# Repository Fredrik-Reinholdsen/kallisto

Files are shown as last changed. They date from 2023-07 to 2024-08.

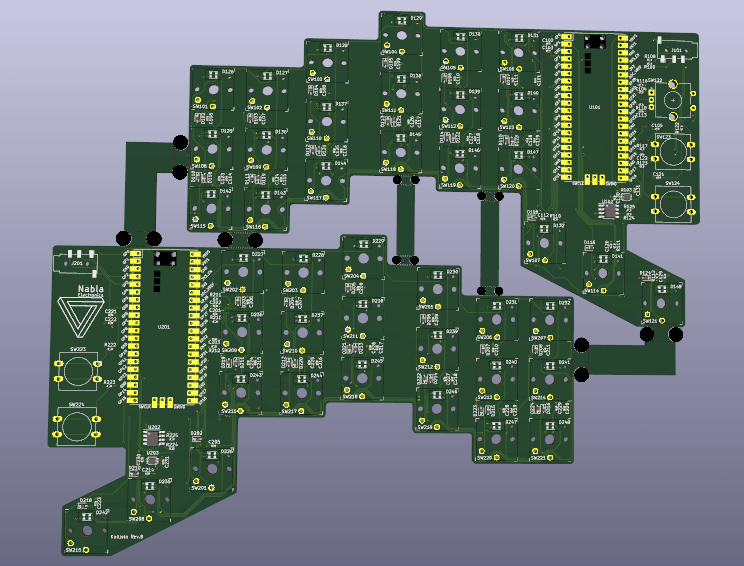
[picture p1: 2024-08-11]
images/kallisto_3dmodel.png

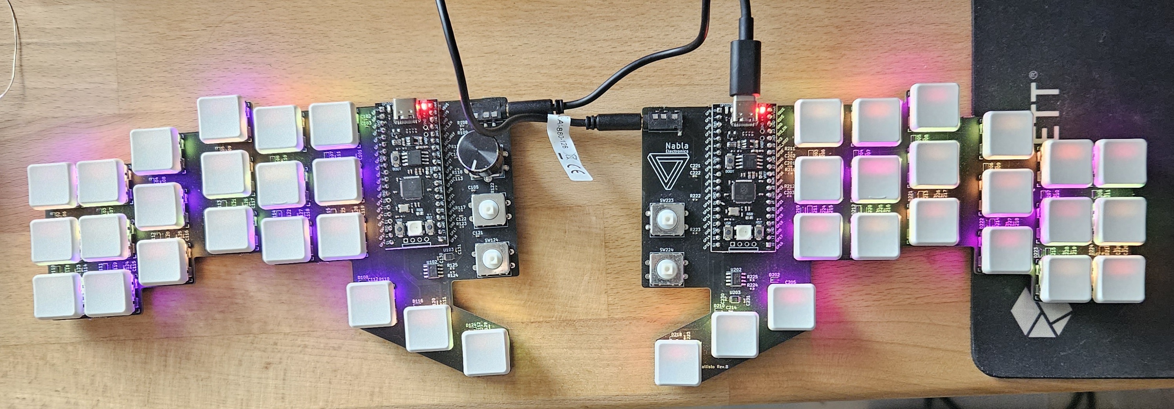
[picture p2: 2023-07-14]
images/kallisto.jpg

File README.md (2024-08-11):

# Kallisto

A custom split keyboard, with custom electronics and firmware.

kallisto

The hardware is based around a variant of the _Raspberry Pi Pico_ board, and the _RP2040_ microcontroller.
The keyboard features:

- 42 Kailh 1350 mechanical keyswitches (21 per half), 4 extra buttons and one rotary encoder.
- Fully programmable key-map were any key can be mapped to any key/media function.
- Key-map Layers
- Custom RGB lighting with adjustable brightness
- Onboard flash memory that hold the key-map.

All electronics were designed using KiCad, and all firmware is written in Rust.

## Key Mapping
Any physical key on the keyboard may be mapped to any key, with or without an additional modifier.
Buttons have a few different press modes, similar to the *QMK* firmware, that you can map separatley to different keys.

The different key press types/events are:
- Press
- Held Press
- Double Press

### Held Press
A held press is when a button is pressed and held, for a set ammount of time (0.5s by default).
If a button has a held press mapping is pressed and then released before the held-time window,
then the regular _Press_ mapping while fire upon the release, not the press.
If another button is pressed before the end of the held-time window, then the held press mapping while fire immediatley,
and the other pressed button will fire right after.
If a button with a held press mapping is pressed and held for more than the held-time window, and no other button is pressed in between,
then the held press key mapping will fire.

## Software Design
The right half of the keyboard connected to the host PC acts as the master, and the the left half as the slave.
Compiling the embedded software will generate two separate binaries, one for the master half, and one for the slave.

The slave software is very light-weight and is basically only reading the button matrix, and communicating the current
button states to the master half vi I2C. This means that the slave, once flashed, should rarely need to be re-programmed since the
vast majority of the more complicated application code is running on the master half.

Below is a figure showing the overall architecture of the software that is running on each half of the keyboard.
```mermaid
flowchart RL
    subgraph Master
        direction BT
        BMR[Button Matrix] --> KEGR(Key Event Generator)
        KEGR -->|Key Event| BEG(Button Event Generator)
        BEG -->|Button Event| BEM(Button Event Mapper)
        BEM -->|USB HID Event| USB(USB HID)
    end

    subgraph Slave
        direction BT
        BML[Button Matrix] --> KEGL(Key Event Generator)
    end

    Slave -->|Key Events| Master
```
### Key Event Generator
The `Key Event Generator` reads the current states of all keyboard buttons from the button matrix driver, and generates key press events.
Either key-down or key-up events, based on the current, and the previous button states. Key press events and IDs are constantly
streamed from the slave to the master half via I2C.
These key events from both halves are then queued on the master, along with a unique button ID for which physical button that triggered the event.

### Button Event Generator
The `Button Event Generator` then reads the incoming key press events, and correspoding button IDs from the key-event queue.
This information is then used to generate `Button Events`. The different kinds are:
- Single Press
- Held Press
- Double Press

A held press is triggered if a button is pressed and held for more than 0.3 seconds, and a double press is generated
if a button is pressed twice within 0.3 seconds (these times are tweakable).

The button events along with the ID of which physical button produced the event are then passed `Button Event Mapper`

### Button Event Mapper
The `Button Event Mapper` then maps the incoming button IDs and button event types to a key-press to be sent to the host PC via USB.
For example, single pressing the z-key might map to `z`, but pressing and hold it might map to `Ctrl`. This mapping for each physical button,
and button event type is fully customizable.

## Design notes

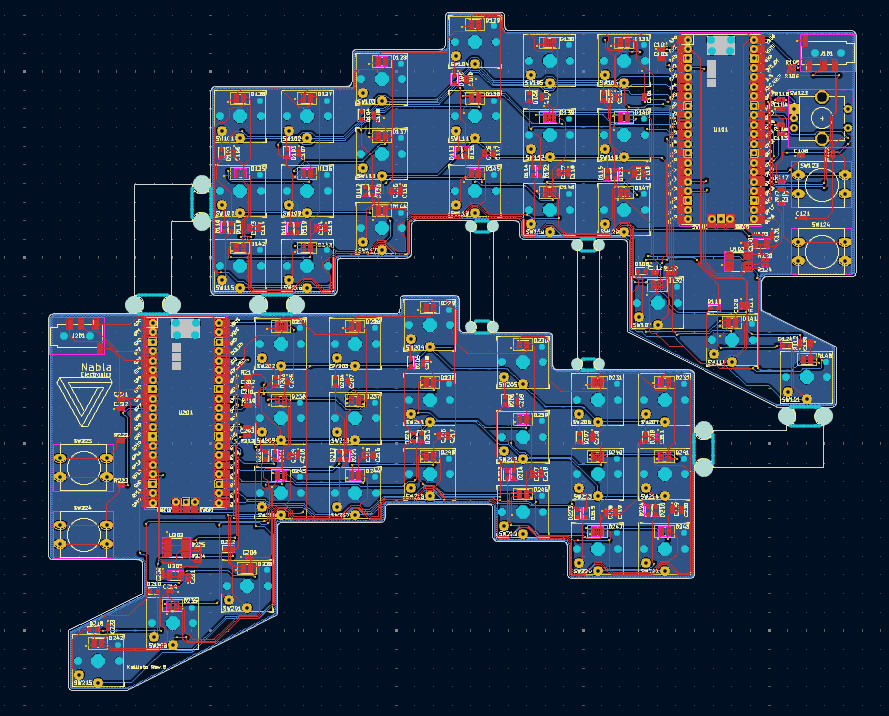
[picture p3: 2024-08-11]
images/kallisto_pcb.png

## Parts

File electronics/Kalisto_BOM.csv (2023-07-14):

Comment | Designator | Footprint | LCSC Part #
100n | C101,C102,C103,C104,C106,C107,C108,C109,C110,C111,C112,C113,C114,C115,C116,C117,C118,C119,C120,C123,C124,C125,C126,C127,C128,C129,C130,C131,C201,C202,C203,C205,C206,C207,C208,C209,C210,C211,C214,C215,C216,C217,C218,C219,C220,C223,C224,C225,C226,C227,C228,C229,C230,C231 | C_0402_1005Metric | C1525
220n | C105,C121,C122,C221,C222 | C_0402_1005Metric | C16772
1N4148 | D102,D103,D104,D105,D106,D107,D108,D110,D111,D112,D113,D114,D115,D116,D118,D119,D120,D121,D122,D123,D124,D202,D203,D204,D205,D206,D207,D208,D210,D211,D212,D213,D214,D215,D216,D218,D219,D220,D221,D222,D223,D224 | D_SOD-323 | C2128
WS2812B_2020 | D126,D127,D128,D129,D130,D131,D132,D135,D136,D137,D138,D139,D140,D141,D142,D143,D144,D145,D146,D147,D148,D226,D227,D228,D229,D230,D231,D232,D235,D236,D237,D238,D239,D240,D241,D242,D243,D244,D245,D246,D247,D248 | LED_WS2812B-2020_PLCC4_2.0x2.0mm | C965555
AudioJack4 | J101,J201 | Jack_3.5mm_PJ320D_Horizontal | C431535
4.7k | R108,R109,R110,R111,R112,R116,R117,R118,R122,R123,R124,R125,R210,R211,R212,R222,R223,R224,R225 | R_0402_1005Metric | C25900
Encoder | SW122 | RotaryEncoder_Alps_EC11E-Switch_Vertical_H20mm_CircularMountingHoles | C470753
SW_SPST | SW123,SW124,SW223,SW224 | SW_PUSH-12mm | C93155
AT24C256C-SSHL-T | U102,U202 | SOIC-8_3.9x4.9mm_P1.27mm | C6482
TXB0102DCU | U103,U203 | VSSOP-8_2.4x2.1mm_P0.5mm | C2677366

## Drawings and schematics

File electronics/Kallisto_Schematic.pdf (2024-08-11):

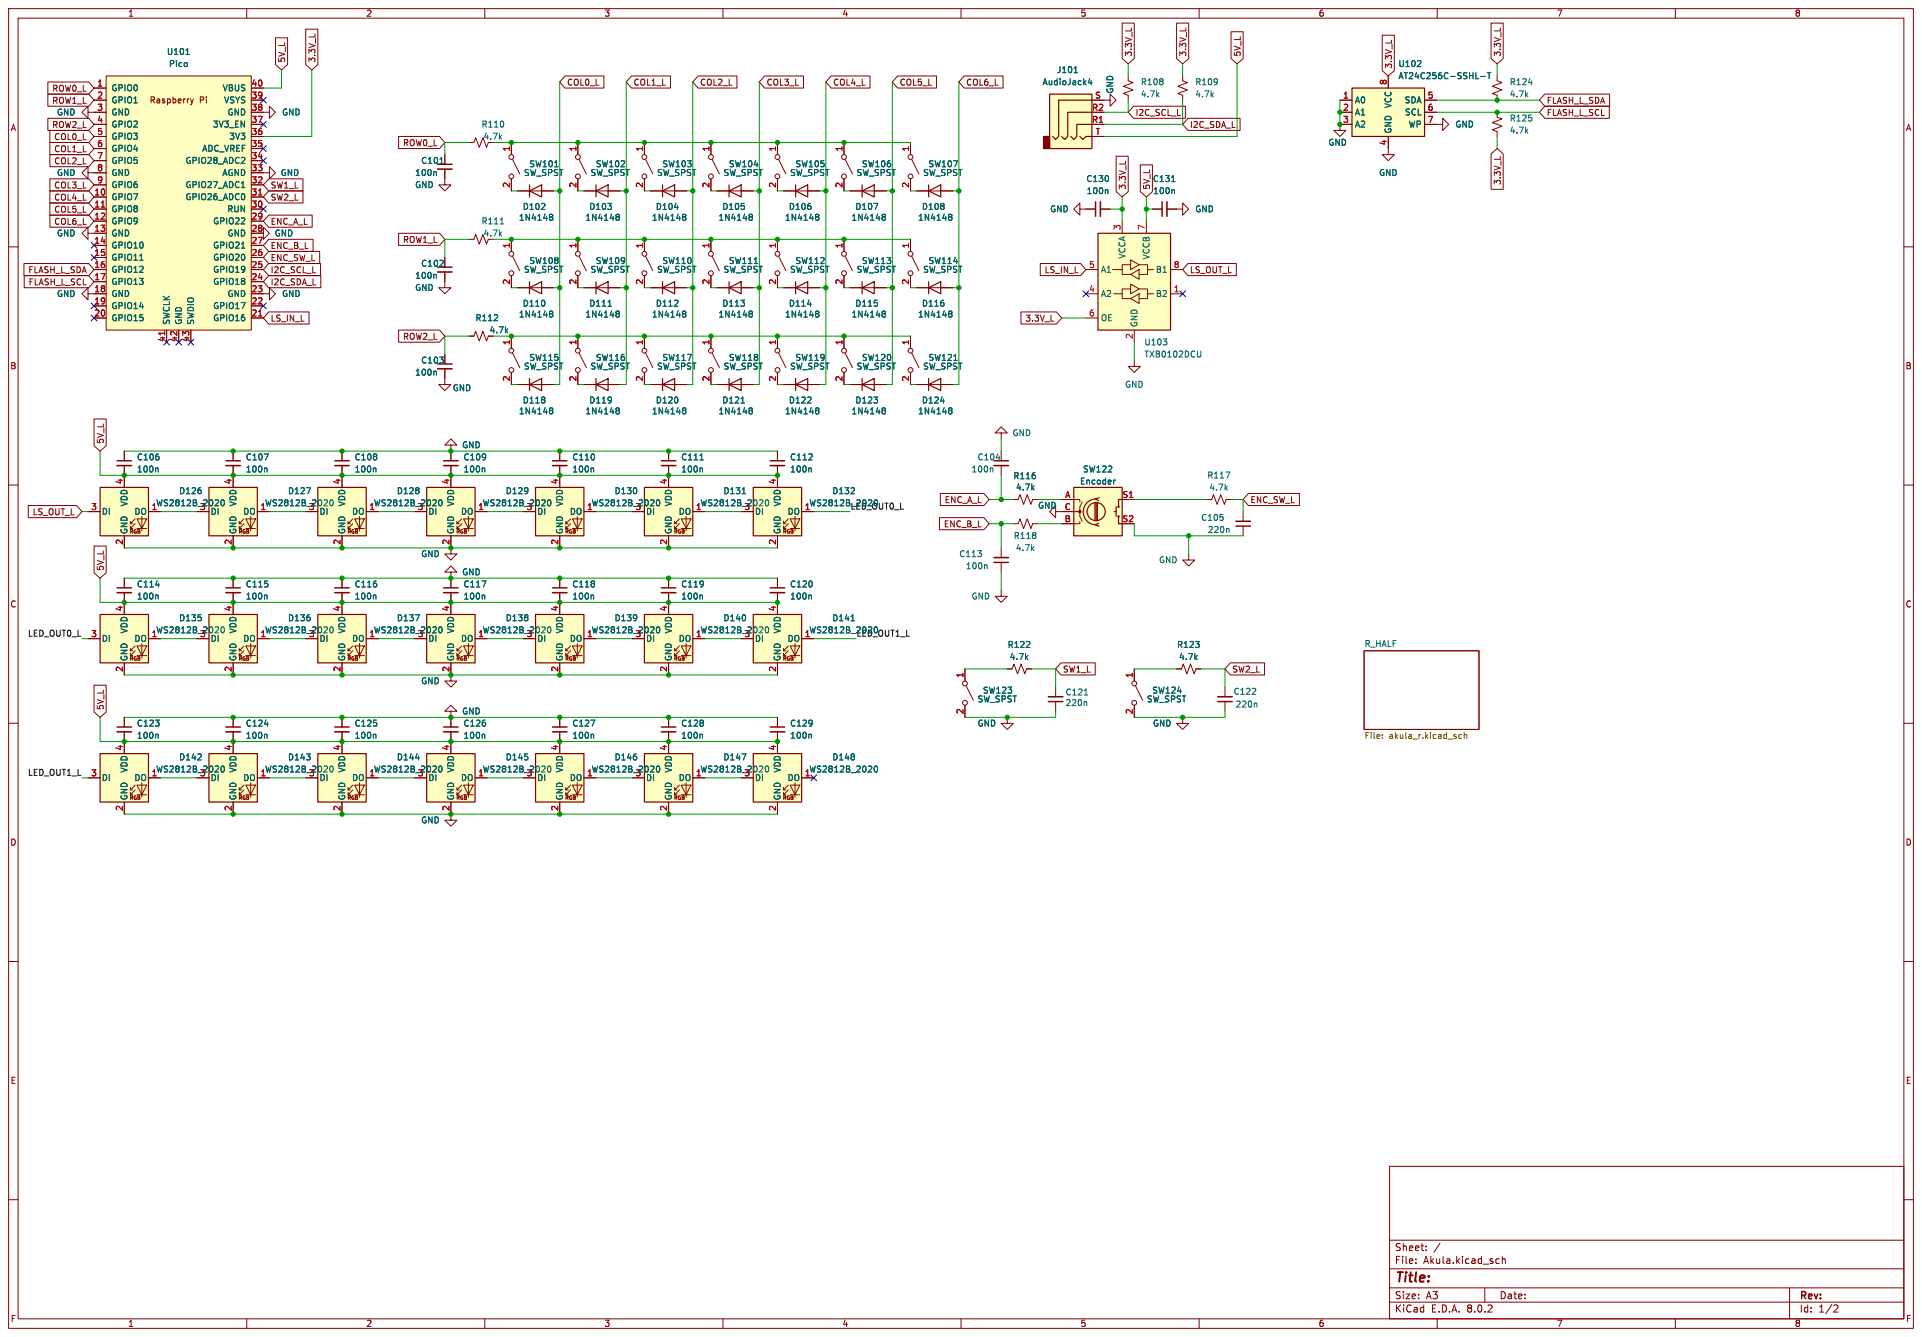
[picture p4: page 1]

4 D129 WS2812B_2020 Raspberry Pi GPIO0 1 GPIO7 10 GPIO8 11 GPIO9 12 GND 13 GPIO10 14 GPIO11 15 GPIO12 16 GPIO13 17 GND 18 GPIO14 19 GPIO1 2 GPIO15 20 GPIO16 21 GPIO17 22 GND 23 GPIO18 24 GPIO19 25 GPIO20 26 GPIO21 27 GND 28 GPIO22 29 GND 3 RUN 30 GPIO26_ADC0 31 GPIO27_ADC1 32 AGND 33 GPIO28_ADC2 34 ADC_VREF 35

4 SDA 5 SCL 6 WP 7 VCC

Id: 1/2 Title: File: Akula.kicad_sch Sheet: /

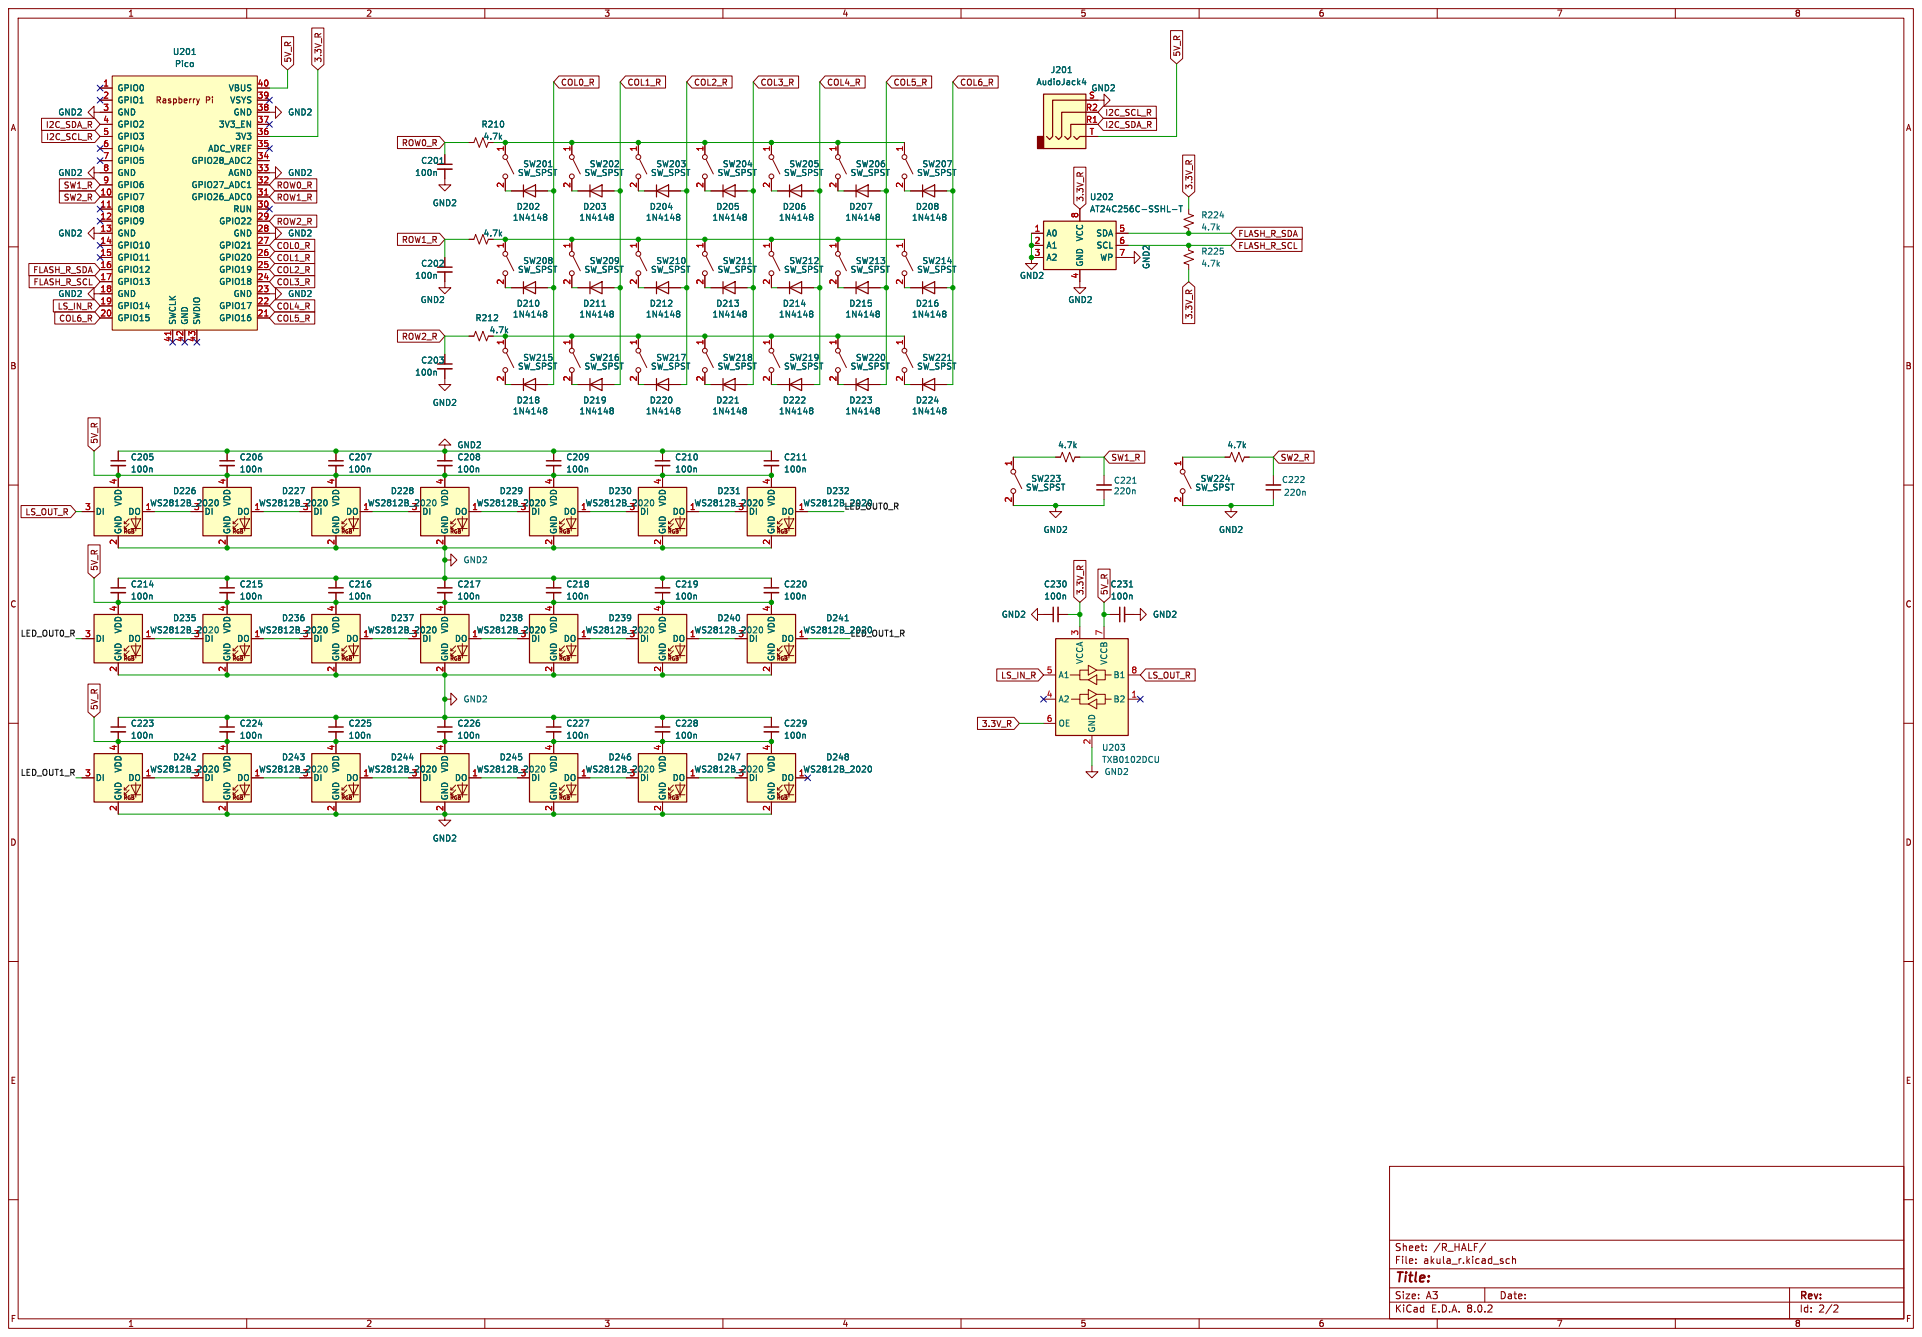
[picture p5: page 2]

4 U201 Pico GPIO0 1 GPIO7 10 GPIO8 11 GPIO9 12 GND 13 GPIO10 14 GPIO11 15 GPIO12 16 GPIO13 17 GND 18 GPIO14 19 GPIO1 2 GPIO15 20 GPIO16 21 GPIO17 22 GND 23 GPIO18 24 GPIO19 25 GPIO20 26 GPIO21 27 GND 28 GPIO22 29 GND 3 RUN 30 GPIO26_ADC0 31 GPIO27_ADC1 32 AGND 33 GPIO28_ADC2 34 ADC_VREF 35

4 SDA 5 SCL 6 WP 7 VCC
FLASH_R_SCL 5V_R

Id: 2/2 Title: File: akula_r.kicad_sch Sheet: /R_HALF/

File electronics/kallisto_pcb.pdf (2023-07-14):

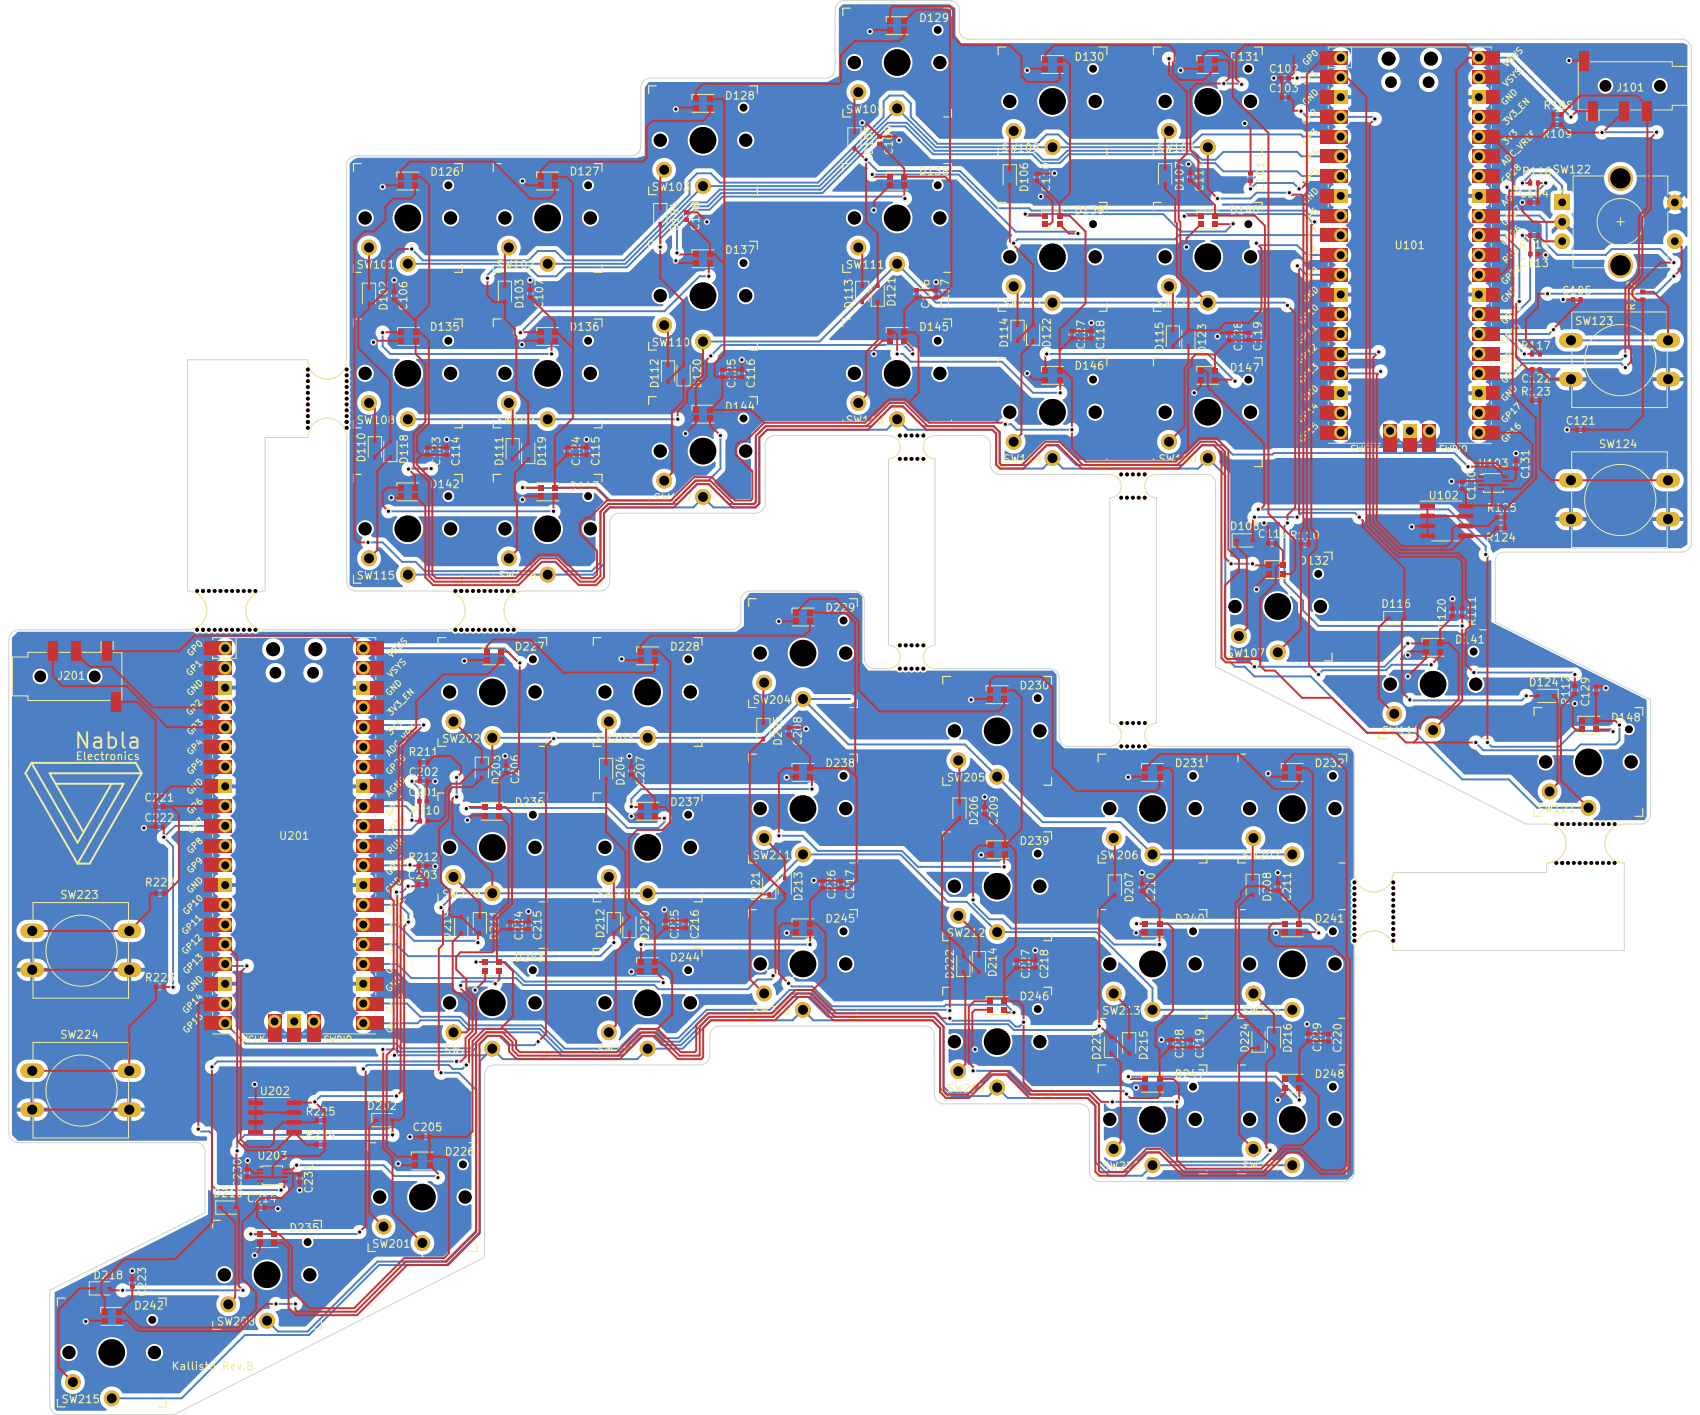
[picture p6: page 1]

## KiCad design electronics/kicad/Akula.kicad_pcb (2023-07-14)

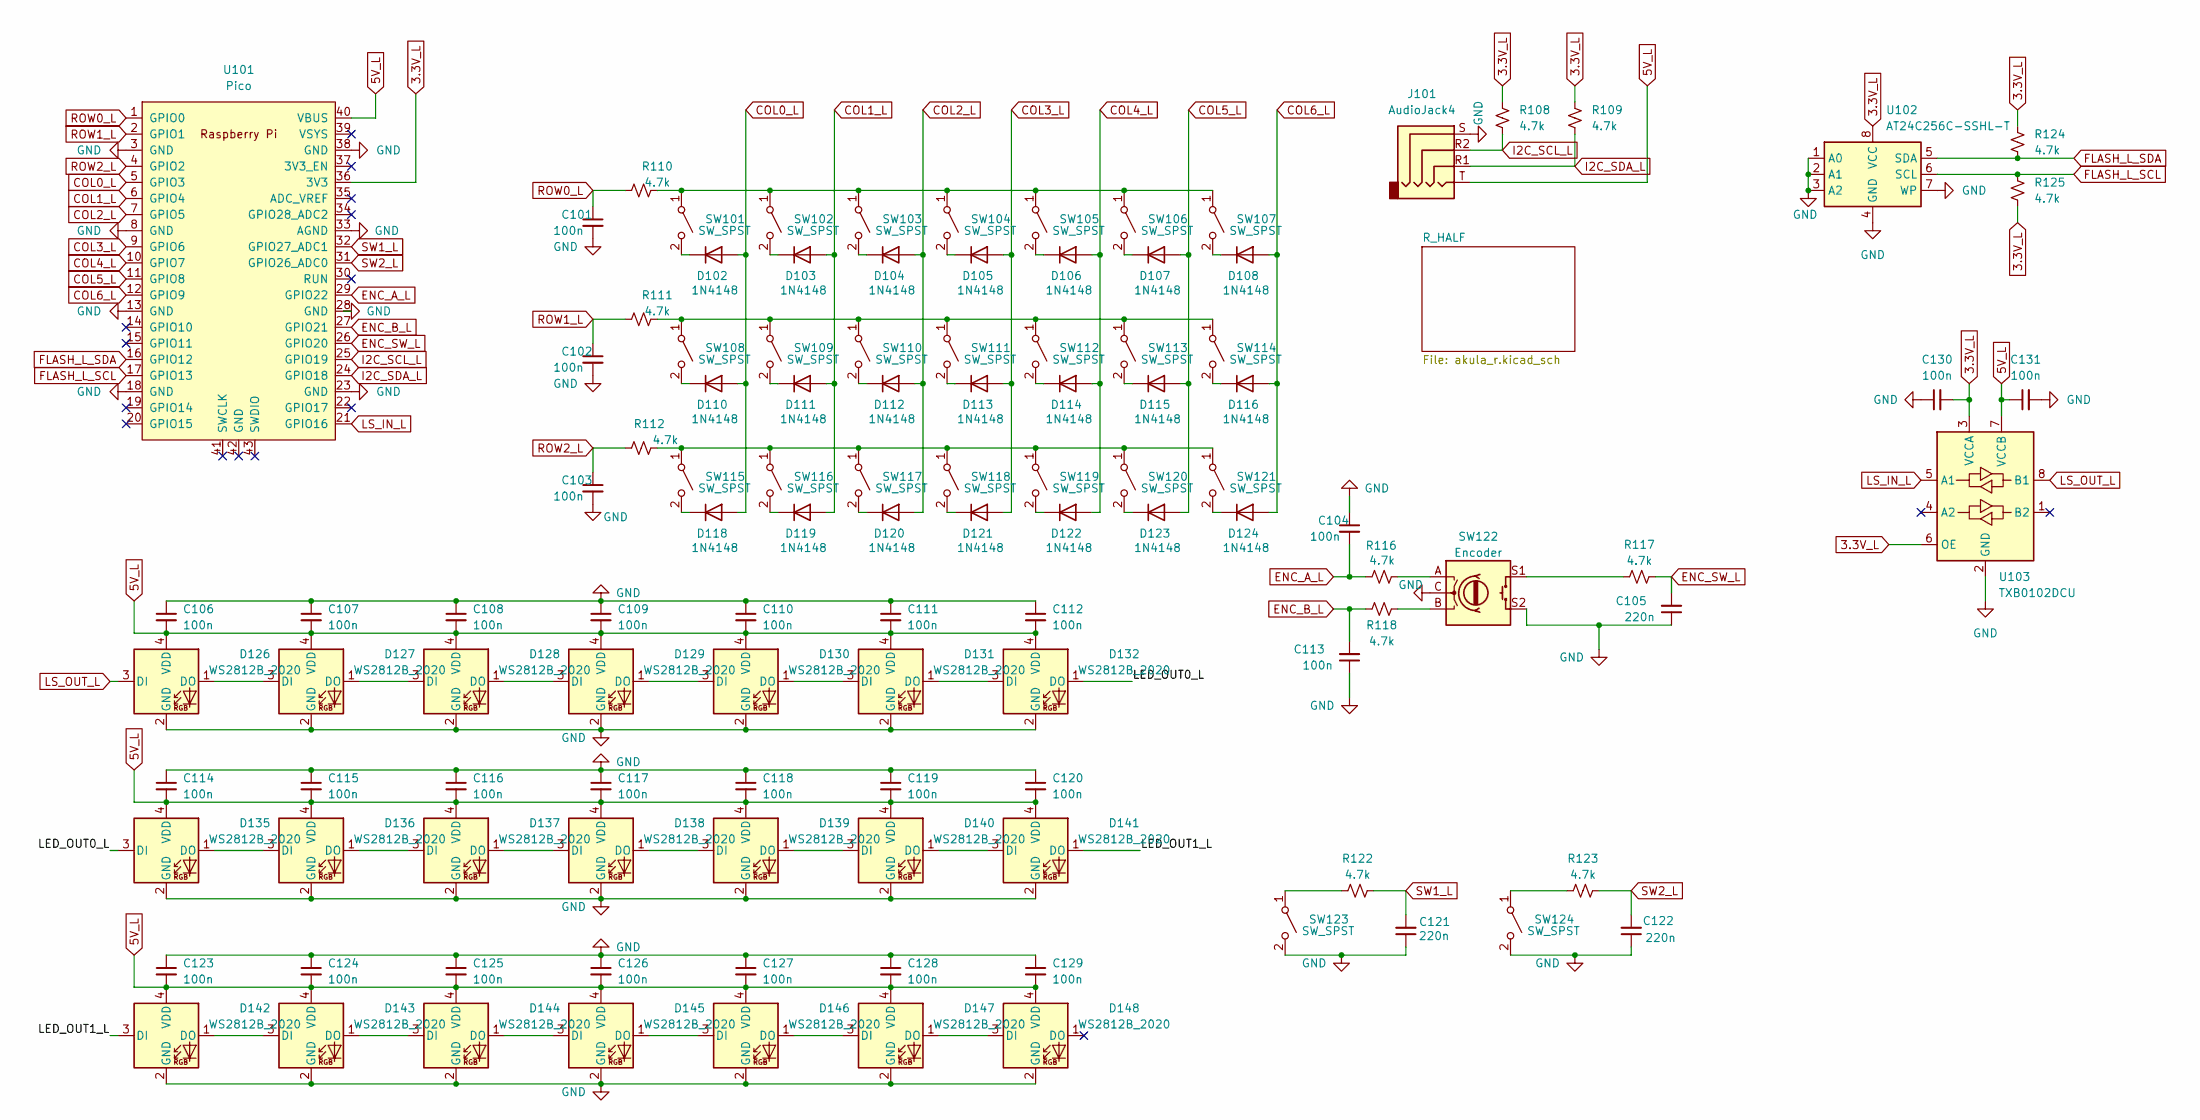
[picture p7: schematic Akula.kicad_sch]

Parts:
C101, C102, C103, C104, C106, C107, C108, C109, C110, C111, C112, C113, C114, C115, C116, C117, C118, C119, C120, C123, C124, C125, C126, C127, C128, C129, C130, C131: 100n; C_0402_1005Metric; JLCPCB Part # C1525
C105, C121, C122: 220n; C_0402_1005Metric; JLCPCB Part # C16772
D102, D103, D104, D105, D106, D107, D108, D110, D111, D112, D113, D114, D115, D116, D118, D119, D120, D121, D122, D123, D124: 1N4148; D_SOD-323; JLCPCB Part # C2128
D126, D127, D128, D129, D130, D131, D132, D135, D136, D137, D138, D139, D140, D141, D142, D143, D144, D145, D146, D147, D148: WS2812B_2020; LED_WS2812B-2020_PLCC4_2.0x2.0mm; JLCPCB Part # C965555
J101: AudioJack4; Jack_3.5mm_PJ320D_Horizontal; JLCPCB Part # C431535
R108, R109, R110, R111, R112, R116, R117, R118, R122, R123, R124, R125: 4.7k; R_0402_1005Metric; JLCPCB Part # C25900
SW101, SW102, SW103, SW104, SW105, SW106, SW107, SW108, SW109, SW110, SW111, SW112, SW113, SW114, SW115, SW116, SW117, SW118, SW119, SW120, SW121: SW_SPST; SW_PG1350
SW122: Encoder; RotaryEncoder_Alps_EC11E-Switch_Vertical_H20mm_CircularMoun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; JLCPCB Part # C470753
SW123, SW124: SW_SPST; SW_PUSH-12mm; JLCPCB Part # C93155
U101: Pico; RPi_Pico_SMD_TH
U102: AT24C256C-SSHL-T; SOIC-8_3.9x4.9mm_P1.27mm; JLCPCB Part # C6482
U103: TXB0102DCU; VSSOP-8_2.4x2.1mm_P0.5mm; JLCPCB Part # C2677366

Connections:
3.3V_L: C130.2, R108.2, R109.2, R124.2, R125.2, U101.36 (3V3), U102.8 (VCC), U103.3 (VCCA), U103.6 (OE)
5V_L: C106.2, C107.2, C108.2, C109.2, C110.2, C111.2, C112.2, C114.2, C115.2, C116.2, C117.2, C118.2, C119.2, C120.2, C123.2, C124.2, C125.2, C126.2, C127.2, C128.2, C129.2, C131.1, D126.4 (VDD), D127.4 (VDD), D128.4 (VDD), D129.4 (VDD), D130.4 (VDD), D131.4 (VDD), D132.4 (VDD), D135.4 (VDD), D136.4 (VDD), D137.4 (VDD), D138.4 (VDD), D139.4 (VDD), D140.4 (VDD), D141.4 (VDD), D142.4 (VDD), D143.4 (VDD), D144.4 (VDD), D145.4 (VDD), D146.4 (VDD), D147.4 (VDD), D148.4 (VDD), J101.T, U101.40 (VBUS), U103.7 (VCCB)
/LED_OUT0_L: D132.1 (DO), D135.3 (DI)
/LED_OUT1_L: D141.1 (DO), D142.3 (DI)
COL0_L: D102.2 (A), D110.2 (A), D118.2 (A), U101.5 (GPIO3)
COL1_L: D103.2 (A), D111.2 (A), D119.2 (A), U101.6 (GPIO4)
COL2_L: D104.2 (A), D112.2 (A), D120.2 (A), U101.7 (GPIO5)
COL3_L: D105.2 (A), D113.2 (A), D121.2 (A), U101.9 (GPIO6)
COL4_L: D106.2 (A), D114.2 (A), D122.2 (A), U101.10 (GPIO7)
COL5_L: D107.2 (A), D115.2 (A), D123.2 (A), U101.11 (GPIO8)
COL6_L: D108.2 (A), D116.2 (A), D124.2 (A), U101.12 (GPIO9)
ENC_A_L: C104.2, R116.2, U101.29 (GPIO22)
ENC_B_L: C113.2, R118.2, U101.27 (GPIO21)
ENC_SW_L: C105.2, R117.1, U101.26 (GPIO20)
FLASH_L_SCL: R125.1, U101.17 (GPIO13), U102.6 (SCL)
FLASH_L_SDA: R124.1, U101.16 (GPIO12), U102.5 (SDA)
GND: C101.2, C102.2, C103.2, C104.1, C105.1, C106.1, C107.1, C108.1, C109.1, C110.1, C111.1, C112.1, C113.1, C114.1, C115.1, C116.1, C117.1, C118.1, C119.1, C120.1, C121.1, C122.1, C123.1, C124.1, C125.1, C126.1, C127.1, C128.1, C129.1, C130.1, C131.2, D126.2 (GND), D127.2 (GND), D128.2 (GND), D129.2 (GND), D130.2 (GND), D131.2 (GND), D132.2 (GND), D135.2 (GND), D136.2 (GND), D137.2 (GND), D138.2 (GND), D139.2 (GND), D140.2 (GND), D141.2 (GND), D142.2 (GND), D143.2 (GND), D144.2 (GND), D145.2 (GND), D146.2 (GND), D147.2 (GND), D148.2 (GND), J101.S, SW122.C, SW122.S2, SW123.2 (B), SW124.2 (B), U101.3 (GND), U101.8 (GND), U101.13 (GND), U101.18 (GND), U101.23 (GND), U101.28 (GND), U101.33 (AGND), U101.38 (GND), U102.1 (A0), U102.2 (A1), U102.3 (A2), U102.4 (GND), U102.7 (WP), U103.2 (GND)
I2C_SCL_L: J101.R2, R108.1, U101.25 (GPIO19)
I2C_SDA_L: J101.R1, R109.1, U101.24 (GPIO18)
LS_IN_L: U101.21 (GPIO16), U103.5 (A1)
LS_OUT_L: D126.3 (DI), U103.8 (B1)
unnamed: D102.1 (K), SW101.2 (B)
unnamed: D103.1 (K), SW102.2 (B)
unnamed: D104.1 (K), SW103.2 (B)
unnamed: D105.1 (K), SW104.2 (B)
unnamed: D106.1 (K), SW105.2 (B)
unnamed: D107.1 (K), SW106.2 (B)
unnamed: D108.1 (K), SW107.2 (B)
unnamed: D110.1 (K), SW108.2 (B)
unnamed: D111.1 (K), SW109.2 (B)
unnamed: D112.1 (K), SW110.2 (B)
unnamed: D113.1 (K), SW111.2 (B)
unnamed: D114.1 (K), SW112.2 (B)
unnamed: D115.1 (K), SW113.2 (B)
unnamed: D116.1 (K), SW114.2 (B)
unnamed: D118.1 (K), SW115.2 (B)
unnamed: D119.1 (K), SW116.2 (B)
unnamed: D120.1 (K), SW117.2 (B)
unnamed: D121.1 (K), SW118.2 (B)
unnamed: D122.1 (K), SW119.2 (B)
unnamed: D123.1 (K), SW120.2 (B)
unnamed: D124.1 (K), SW121.2 (B)
unnamed: D126.1 (DO), D127.3 (DI)
unnamed: D127.1 (DO), D128.3 (DI)
unnamed: D128.1 (DO), D129.3 (DI)
unnamed: D129.1 (DO), D130.3 (DI)
unnamed: D130.1 (DO), D131.3 (DI)
unnamed: D131.1 (DO), D132.3 (DI)
unnamed: D135.1 (DO), D136.3 (DI)
unnamed: D136.1 (DO), D137.3 (DI)
unnamed: D137.1 (DO), D138.3 (DI)
unnamed: D138.1 (DO), D139.3 (DI)
unnamed: D139.1 (DO), D140.3 (DI)
unnamed: D140.1 (DO), D141.3 (DI)
unnamed: D142.1 (DO), D143.3 (DI)
unnamed: D143.1 (DO), D144.3 (DI)
unnamed: D144.1 (DO), D145.3 (DI)
unnamed: D145.1 (DO), D146.3 (DI)
unnamed: D146.1 (DO), D147.3 (DI)
unnamed: D147.1 (DO), D148.3 (DI)
unnamed: R116.1, SW122.A
unnamed: R117.2, SW122.S1
unnamed: R118.1, SW122.B
unnamed: R110.1, SW101.1 (A), SW102.1 (A), SW103.1 (A), SW104.1 (A), SW105.1 (A), SW106.1 (A), SW107.1 (A)
unnamed: R111.1, SW108.1 (A), SW109.1 (A), SW110.1 (A), SW111.1 (A), SW112.1 (A), SW113.1 (A), SW114.1 (A)
unnamed: R112.1, SW115.1 (A), SW116.1 (A), SW117.1 (A), SW118.1 (A), SW119.1 (A), SW120.1 (A), SW121.1 (A)
unnamed: R122.2, SW123.1 (A)
unnamed: R123.2, SW124.1 (A)
ROW0_L: C101.1, R110.2, U101.1 (GPIO0)
ROW1_L: C102.1, R111.2, U101.2 (GPIO1)
ROW2_L: C103.1, R112.2, U101.4 (GPIO2)
SW1_L: C121.2, R122.1, U101.32 (GPIO27_ADC1)
SW2_L: C122.2, R123.1, U101.31 (GPIO26_ADC0)

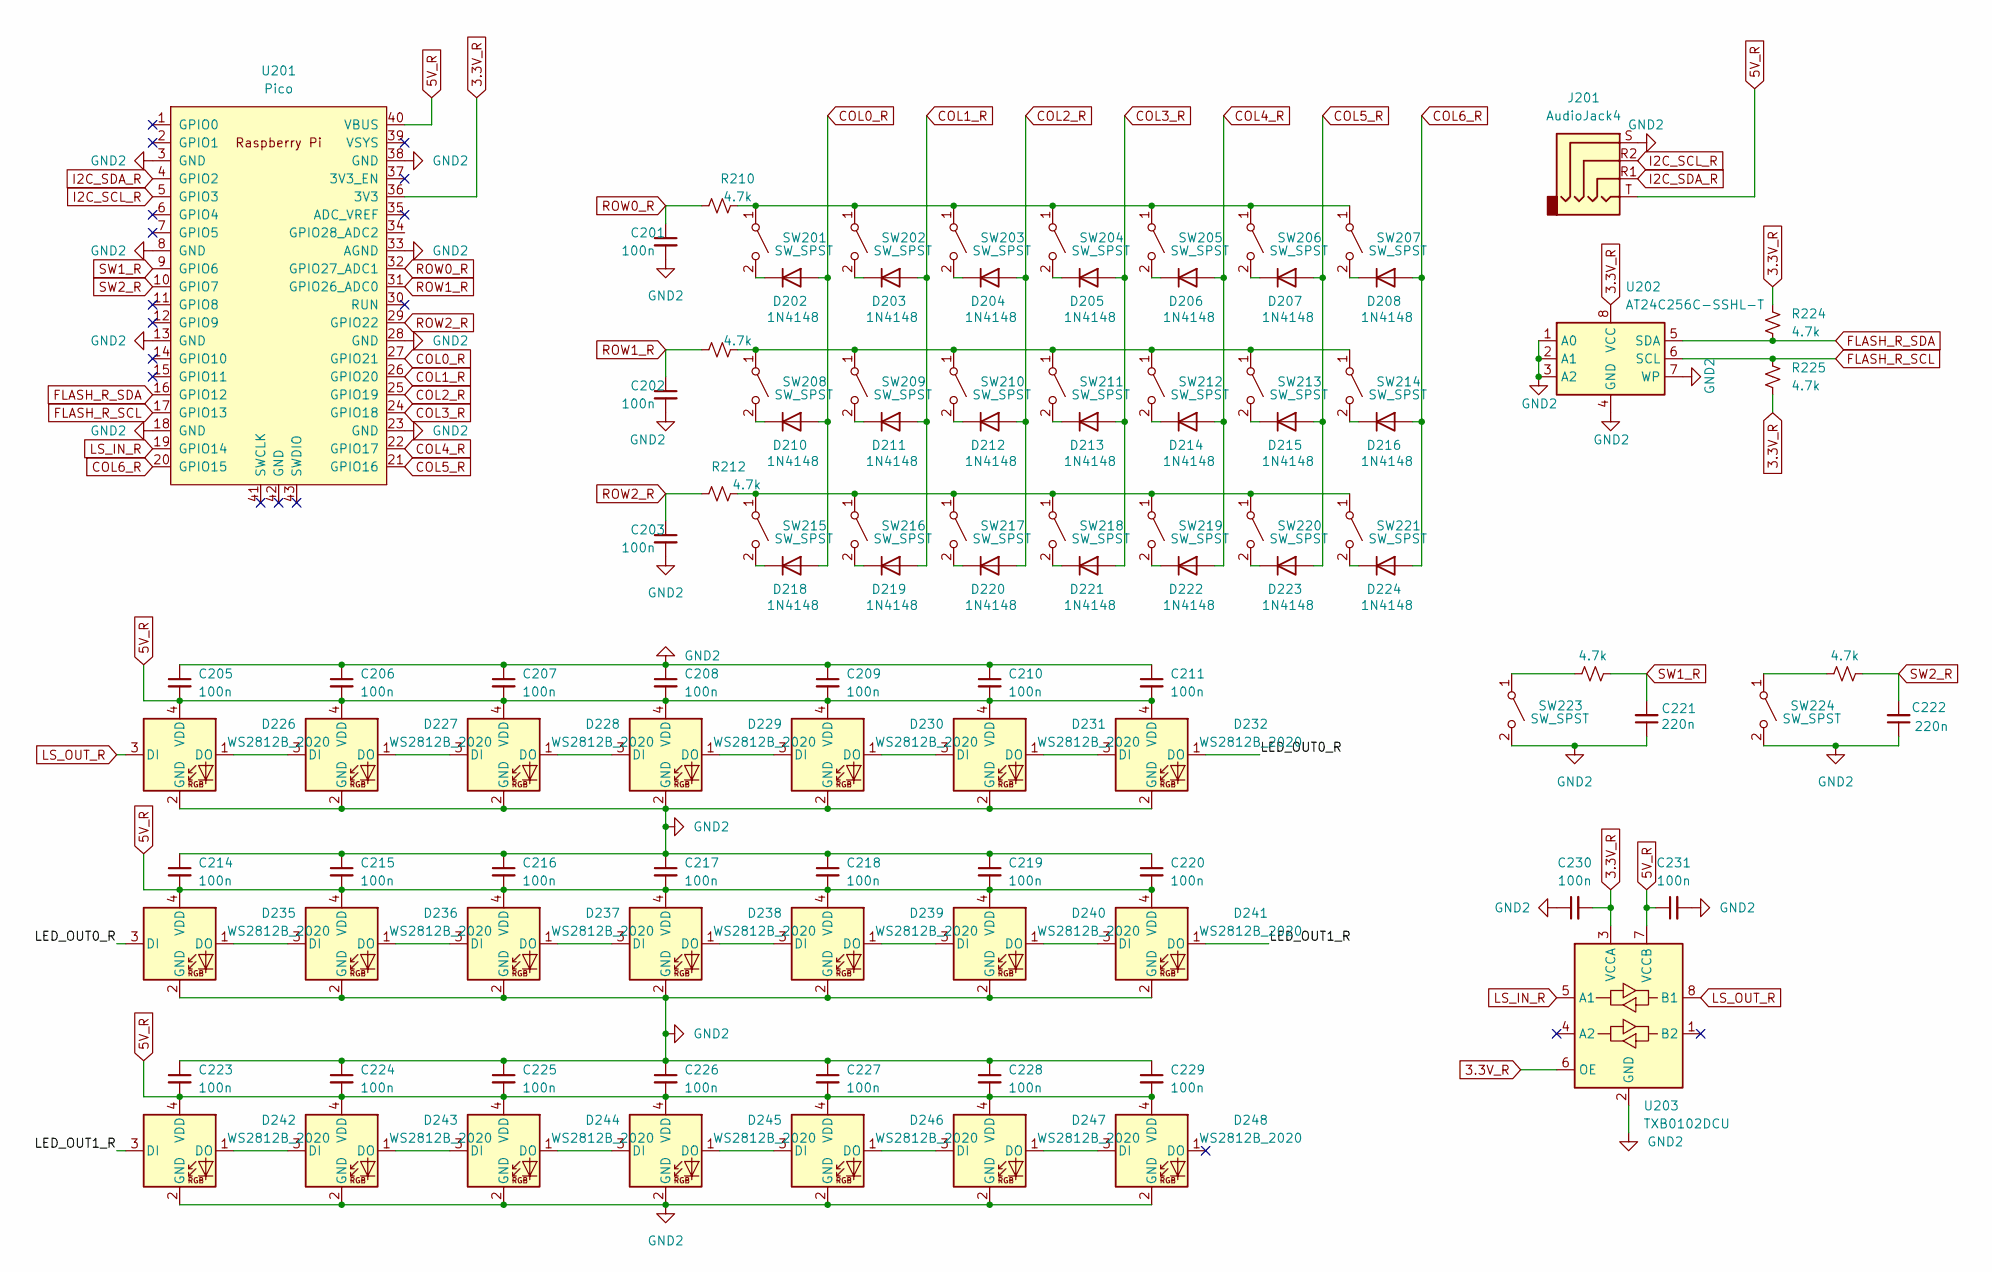
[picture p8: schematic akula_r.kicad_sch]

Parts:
C201, C202, C203, C205, C206, C207, C208, C209, C210, C211, C214, C215, C216, C217, C218, C219, C220, C223, C224, C225, C226, C227, C228, C229, C230, C231: 100n; C_0402_1005Metric; JLCPCB Part # C1525
C221, C222: 220n; C_0402_1005Metric; JLCPCB Part # C16772
D202, D203, D204, D205, D206, D207, D208, D210, D211, D212, D213, D214, D215, D216, D218, D219, D220, D221, D222, D223, D224: 1N4148; D_SOD-323; JLCPCB Part # C2128
D226, D227, D228, D229, D230, D231, D232, D235, D236, D237, D238, D239, D240, D241, D242, D243, D244, D245, D246, D247, D248: WS2812B_2020; LED_WS2812B-2020_PLCC4_2.0x2.0mm; JLCPCB Part # C965555
J201: AudioJack4; Jack_3.5mm_PJ320D_Horizontal; JLCPCB Part # C431535
R210, R211, R212, R222, R223, R224, R225: 4.7k; R_0402_1005Metric; JLCPCB Part # C25900
SW201, SW202, SW203, SW204, SW205, SW206, SW207, SW208, SW209, SW210, SW211, SW212, SW213, SW214, SW215, SW216, SW217, SW218, SW219, SW220, SW221: SW_SPST; SW_PG1350
SW223, SW224: SW_SPST; SW_PUSH-12mm; JLCPCB Part # C93155
U201: Pico; RPi_Pico_SMD_TH
U202: AT24C256C-SSHL-T; SOIC-8_3.9x4.9mm_P1.27mm; JLCPCB Part # C6482
U203: TXB0102DCU; VSSOP-8_2.4x2.1mm_P0.5mm; JLCPCB Part # C2677366

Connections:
3.3V_R: C230.2, R224.2, R225.2, U201.36 (3V3), U202.8 (VCC), U203.3 (VCCA), U203.6 (OE)
5V_R: C205.2, C206.2, C207.2, C208.2, C209.2, C210.2, C211.2, C214.2, C215.2, C216.2, C217.2, C218.2, C219.2, C220.2, C223.2, C224.2, C225.2, C226.2, C227.2, C228.2, C229.2, C231.1, D226.4 (VDD), D227.4 (VDD), D228.4 (VDD), D229.4 (VDD), D230.4 (VDD), D231.4 (VDD), D232.4 (VDD), D235.4 (VDD), D236.4 (VDD), D237.4 (VDD), D238.4 (VDD), D239.4 (VDD), D240.4 (VDD), D241.4 (VDD), D242.4 (VDD), D243.4 (VDD), D244.4 (VDD), D245.4 (VDD), D246.4 (VDD), D247.4 (VDD), D248.4 (VDD), J201.T, U201.40 (VBUS), U203.7 (VCCB)
/R_HALF/LED_OUT0_R: D232.1 (DO), D235.3 (DI)
/R_HALF/LED_OUT1_R: D241.1 (DO), D242.3 (DI)
COL0_R: D202.2 (A), D210.2 (A), D218.2 (A), U201.27 (GPIO21)
COL1_R: D203.2 (A), D211.2 (A), D219.2 (A), U201.26 (GPIO20)
COL2_R: D204.2 (A), D212.2 (A), D220.2 (A), U201.25 (GPIO19)
COL3_R: D205.2 (A), D213.2 (A), D221.2 (A), U201.24 (GPIO18)
COL4_R: D206.2 (A), D214.2 (A), D222.2 (A), U201.22 (GPIO17)
COL5_R: D207.2 (A), D215.2 (A), D223.2 (A), U201.21 (GPIO16)
COL6_R: D208.2 (A), D216.2 (A), D224.2 (A), U201.20 (GPIO15)
FLASH_R_SCL: R225.1, U201.17 (GPIO13), U202.6 (SCL)
FLASH_R_SDA: R224.1, U201.16 (GPIO12), U202.5 (SDA)
GND2: C201.2, C202.2, C203.2, C205.1, C206.1, C207.1, C208.1, C209.1, C210.1, C211.1, C214.1, C215.1, C216.1, C217.1, C218.1, C219.1, C220.1, C221.1, C222.1, C223.1, C224.1, C225.1, C226.1, C227.1, C228.1, C229.1, C230.1, C231.2, D226.2 (GND), D227.2 (GND), D228.2 (GND), D229.2 (GND), D230.2 (GND), D231.2 (GND), D232.2 (GND), D235.2 (GND), D236.2 (GND), D237.2 (GND), D238.2 (GND), D239.2 (GND), D240.2 (GND), D241.2 (GND), D242.2 (GND), D243.2 (GND), D244.2 (GND), D245.2 (GND), D246.2 (GND), D247.2 (GND), D248.2 (GND), J201.S, SW223.2 (B), SW224.2 (B), U201.3 (GND), U201.8 (GND), U201.13 (GND), U201.18 (GND), U201.23 (GND), U201.28 (GND), U201.33 (AGND), U201.38 (GND), U202.1 (A0), U202.2 (A1), U202.3 (A2), U202.4 (GND), U202.7 (WP), U203.2 (GND)
I2C_SCL_R: J201.R2, U201.5 (GPIO3)
I2C_SDA_R: J201.R1, U201.4 (GPIO2)
LS_IN_R: U201.19 (GPIO14), U203.5 (A1)
LS_OUT_R: D226.3 (DI), U203.8 (B1)
unnamed: D202.1 (K), SW201.2 (B)
unnamed: D203.1 (K), SW202.2 (B)
unnamed: D204.1 (K), SW203.2 (B)
unnamed: D205.1 (K), SW204.2 (B)
unnamed: D206.1 (K), SW205.2 (B)
unnamed: D207.1 (K), SW206.2 (B)
unnamed: D208.1 (K), SW207.2 (B)
unnamed: D210.1 (K), SW208.2 (B)
unnamed: D211.1 (K), SW209.2 (B)
unnamed: D212.1 (K), SW210.2 (B)
unnamed: D213.1 (K), SW211.2 (B)
unnamed: D214.1 (K), SW212.2 (B)
unnamed: D215.1 (K), SW213.2 (B)
unnamed: D216.1 (K), SW214.2 (B)
unnamed: D218.1 (K), SW215.2 (B)
unnamed: D219.1 (K), SW216.2 (B)
unnamed: D220.1 (K), SW217.2 (B)
unnamed: D221.1 (K), SW218.2 (B)
unnamed: D222.1 (K), SW219.2 (B)
unnamed: D223.1 (K), SW220.2 (B)
unnamed: D224.1 (K), SW221.2 (B)
unnamed: D226.1 (DO), D227.3 (DI)
unnamed: D227.1 (DO), D228.3 (DI)
unnamed: D228.1 (DO), D229.3 (DI)
unnamed: D229.1 (DO), D230.3 (DI)
unnamed: D230.1 (DO), D231.3 (DI)
unnamed: D231.1 (DO), D232.3 (DI)
unnamed: D235.1 (DO), D236.3 (DI)
unnamed: D236.1 (DO), D237.3 (DI)
unnamed: D237.1 (DO), D238.3 (DI)
unnamed: D238.1 (DO), D239.3 (DI)
unnamed: D239.1 (DO), D240.3 (DI)
unnamed: D240.1 (DO), D241.3 (DI)
unnamed: D242.1 (DO), D243.3 (DI)
unnamed: D243.1 (DO), D244.3 (DI)
unnamed: D244.1 (DO), D245.3 (DI)
unnamed: D245.1 (DO), D246.3 (DI)
unnamed: D246.1 (DO), D247.3 (DI)
unnamed: D247.1 (DO), D248.3 (DI)
unnamed: R210.1, SW201.1 (A), SW202.1 (A), SW203.1 (A), SW204.1 (A), SW205.1 (A), SW206.1 (A), SW207.1 (A)
unnamed: R211.1, SW208.1 (A), SW209.1 (A), SW210.1 (A), SW211.1 (A), SW212.1 (A), SW213.1 (A), SW214.1 (A)
unnamed: R212.1, SW215.1 (A), SW216.1 (A), SW217.1 (A), SW218.1 (A), SW219.1 (A), SW220.1 (A), SW221.1 (A)
unnamed: R222.2, SW223.1 (A)
unnamed: R223.2, SW224.1 (A)
ROW0_R: C201.1, R210.2, U201.32 (GPIO27_ADC1)
ROW1_R: C202.1, R211.2, U201.31 (GPIO26_ADC0)
ROW2_R: C203.1, R212.2, U201.29 (GPIO22)
SW1_R: C221.2, R222.1, U201.9 (GPIO6)
SW2_R: C222.2, R223.1, U201.10 (GPIO7)

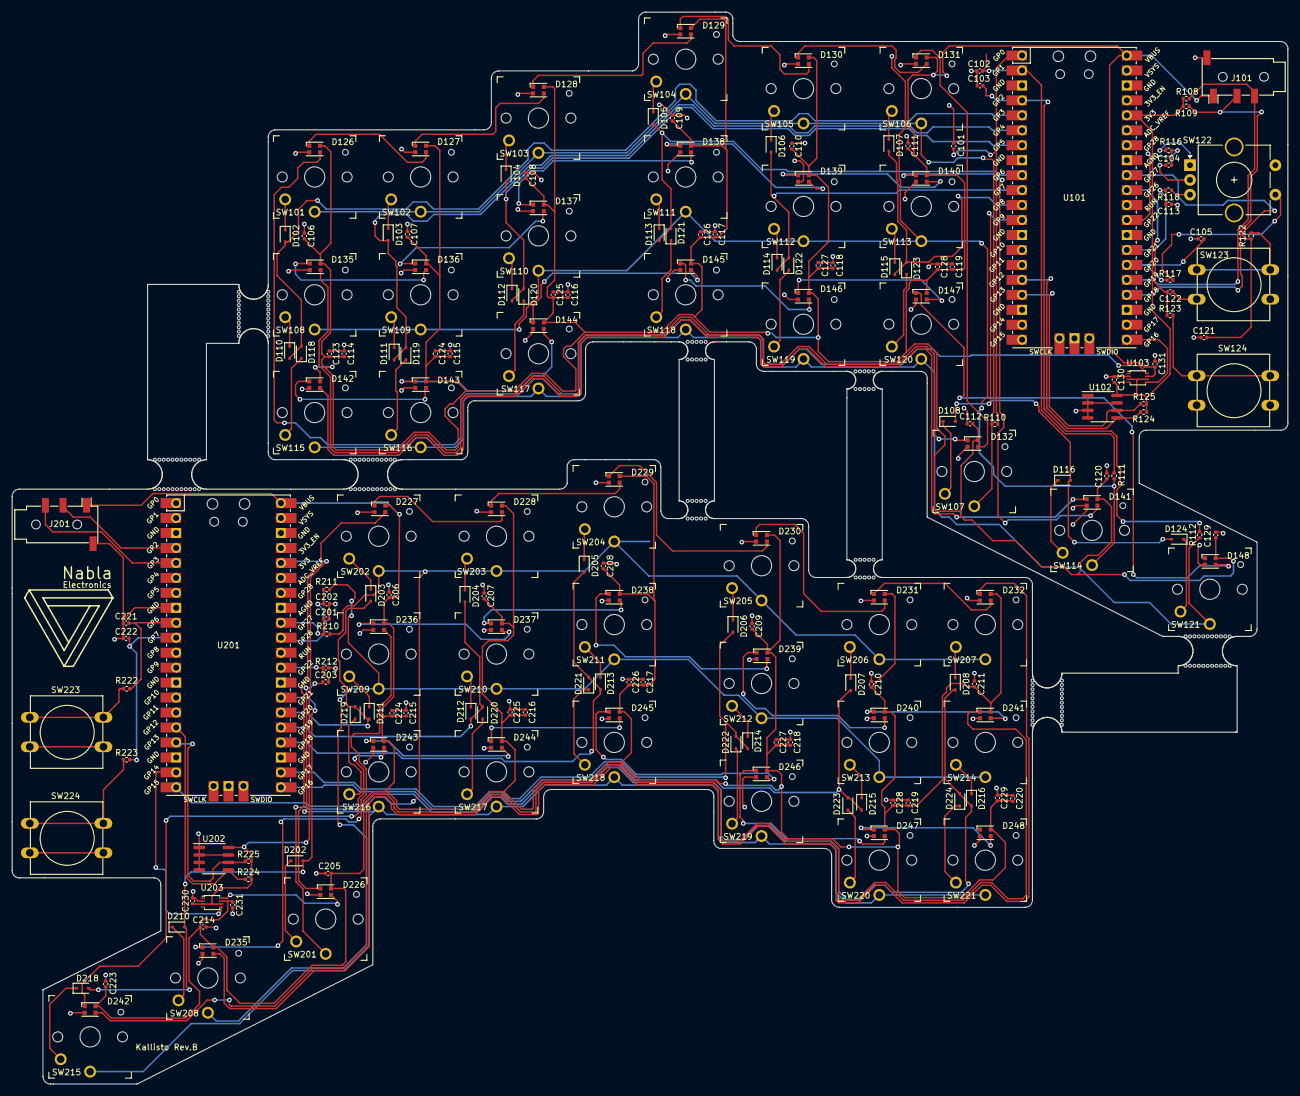
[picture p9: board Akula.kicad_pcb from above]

Board: 2 copper layers, 216.6 x 182.0 mm, 226 parts (0 on the bottom side), 140 nets.

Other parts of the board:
mouse-bite-3mm-slot, mouse-bite-3mm-slot#2, mouse-bite-3mm-slot#3, mouse-bite-3mm-slot#4: VAL**; mouse-bite-3mm-slot
mouse-bite-5mm-slot, mouse-bite-5mm-slot#2, mouse-bite-5mm-slot#3, mouse-bite-5mm-slot#4, mouse-bite-5mm-slot#5: VAL**; mouse-bite-5mm-slot

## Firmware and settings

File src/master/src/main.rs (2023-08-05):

#![no_std]
#![no_main]

pub mod key_map;

// The macro for our start-up function
use rp_pico::entry;

// Ensure we halt the program on panic (if we don't mention this crate it won't
// be linked)
use panic_halt as _;

// Pull in any important traits
use rp_pico::hal::prelude::*;

// A shorter alias for the Peripheral Access Crate, which provides low-level
// register access
use rp_pico::hal::{self, pac};

// Import the Timer for Ws2812:
use rp_pico::hal::timer::Timer;
use hal::i2c::I2C;
use hal::gpio::PinState;

// A shorter alias for the Hardware Abstraction Layer, which provides
// higher-level drivers.
use kallisto_components::keyboard::key_matrix::KeyMatrix;
use kallisto_components::keyboard::keyboard::LayeredKeyboard;
use kallisto_components::keyboard::types::*;
use crate::key_map::*;

use embedded_hal::digital::v2::{InputPin, OutputPin};
use embedded_hal::timer::CountDown;
use embedded_hal::blocking::i2c::Read;

use heapless::spsc::Queue;
use usb_device::class_prelude::*;
use fugit::ExtU32;
use fugit::RateExtU32;

use usbd_human_interface_device as hid;
use hid::page::Keyboard;
use hid::prelude::*;

use usb_device::{class_prelude::*, prelude::*};
use usbd_serial::SerialPort;
use core::fmt::Write;
use usb_device::class_prelude::*;
use usb_device::prelude::*;

use hal::pio::PIOExt;
use smart_leds::{brightness, SmartLedsWrite, RGB8};
use ws2812_pio::Ws2812;

// Currently 3 consecutive LEDs are driven by this example
// to keep the power draw compatible with USB:
const STRIP_LEN: usize = 21;
const N_KEYS: usize = 42;

#[entry]
fn main() -> ! {
    // Grab our singleton objects
    let mut pac = pac::Peripherals::take().unwrap();
    let core = pac::CorePeripherals::take().unwrap();

    // Set up the watchdog driver - needed by the clock setup code
    let mut watchdog = hal::Watchdog::new(pac.WATCHDOG);

    // Configure the clocks
    //
    // The default is to generate a 125 MHz system clock
    let clocks = hal::clocks::init_clocks_and_plls(
        rp_pico::XOSC_CRYSTAL_FREQ,
        pac.XOSC,
        pac.CLOCKS,
        pac.PLL_SYS,
        pac.PLL_USB,
        &mut pac.RESETS,
        &mut watchdog,
    )
    .ok()
    .unwrap();

    // The single-cycle I/O block controls our GPIO pins
    let sio = hal::Sio::new(pac.SIO);

    // Set the pins up according to their function on this particular board
    let pins = rp_pico::Pins::new(
        pac.IO_BANK0,
        pac.PADS_BANK0,
        sio.gpio_bank0,
        &mut pac.RESETS,
    );


    let mut timer = Timer::new(pac.TIMER, &mut pac.RESETS);

    let mut delay = cortex_m::delay::Delay::new(core.SYST, clocks.system_clock.freq().to_Hz());

    // Set up smart leds
    let sin = hal::rom_data::float_funcs::fsin::ptr();

    let (mut pio, sm0, _, _, _) = pac.PIO0.split(&mut pac.RESETS);

    let usb_bus = UsbBusAllocator::new(hal::usb::UsbBus::new(
        pac.USBCTRL_REGS,
        pac.USBCTRL_DPRAM,
        clocks.usb_clock,
        true,
        &mut pac.RESETS,
    ));

    let mut keyboard = UsbHidClassBuilder::new()
        .add_device(
            usbd_human_interface_device::device::keyboard::NKROBootKeyboardConfig::default(),
        )
        .build(&usb_bus);

    //https://pid.codes
    let mut usb_dev = UsbDeviceBuilder::new(&usb_bus, UsbVidPid(0x1209, 0x0001))
        .manufacturer("Nabla Electronics")
        .product("Kallisto")
        .serial_number("002")
        .build();


    // Instanciate a Ws2812 LED strip:
    let mut ws = Ws2812::new(
        // Use pin 6 on the Raspberry Pi Pico (which is GPIO4 of the rp2040 chip)
        // for the LED data output:
        pins.gpio14.into_mode(),
        &mut pio,
        sm0,
        clocks.peripheral_clock.freq(),
        timer.count_down(),
    );

    // Set up i2c
    let sda_pin = pins.gpio2.into_mode::<hal::gpio::FunctionI2C>();
    let scl_pin = pins.gpio3.into_mode::<hal::gpio::FunctionI2C>();

    let mut i2c = I2C::new_controller(
        pac.I2C1,
        sda_pin,
        scl_pin,
        400.kHz(),
        &mut pac.RESETS,
        125_000_000.Hz()
    );
    
    // Set up all pins
    let mut row_pin_0 = pins.gpio27.into_push_pull_output();
    let mut row_pin_1 = pins.gpio26.into_push_pull_output();
    let mut row_pin_2 = pins.gpio22.into_push_pull_output();

    // Setting the output slew rate to fast is absolutley 
    // needed in order to prevent row cross-talk
    row_pin_0.set_slew_rate(hal::gpio::OutputSlewRate::Fast);
    row_pin_1.set_slew_rate(hal::gpio::OutputSlewRate::Fast);
    row_pin_2.set_slew_rate(hal::gpio::OutputSlewRate::Fast);

    // Set up our pins for the key matrix
    let mut row_pins: &mut [&mut dyn OutputPin<Error = core::convert::Infallible>] = &mut [
        &mut row_pin_0,
        &mut row_pin_1,
        &mut row_pin_2,
    ];

    let col_pins: &[&dyn InputPin<Error = core::convert::Infallible>] = &[
        &pins.gpio21.into_pull_up_input(),
        &pins.gpio20.into_pull_up_input(),
        &pins.gpio19.into_pull_up_input(),
        &pins.gpio18.into_pull_up_input(),
        &pins.gpio17.into_pull_up_input(),
        &pins.gpio16.into_pull_up_input(),
        &pins.gpio15.into_pull_up_input(),
    ];

    let mut led_pin = pins.led.into_push_pull_output();
    let mut key_matrix = KeyMatrix::new(&timer);
    let mut event_queue = Queue::<Keyboard, 32>::new();
    let (tx, mut rx) = event_queue.split();
    let mut kallisto = LayeredKeyboard::new(
        &timer,
        [BASE_LAYER, SYMBOL_LAYER, NUM_LAYER, [None; N_KEYS], [None; N_KEYS]],
        tx,
    );


    let mut leds: [RGB8; STRIP_LEN] = [(0, 0, 0).into(); STRIP_LEN];
    let mut t = 0.0;
    let strip_brightness = 64u8; // Limit brightness to 64/256

    // Slow down timer by this factor (0.1 will result in 10 seconds):
    let animation_speed = 0.1;


    let mut keyboard_timer = timer.count_down();
    let mut tick_timer = timer.count_down();
    let mut led_timer = timer.count_down();

    led_timer.start(17.millis());
    keyboard_timer.start(1.millis());
    tick_timer.start(1.millis());

    let mut i2c_buf: [u8; 4] = [0; 4];
    let mut i: usize;
    let mut report_buf: [Keyboard; 32];

    led_pin.set_high().unwrap();
    delay.delay_ms(1000);
    led_pin.set_low().unwrap();

    loop {

        if tick_timer.wait().is_ok() {
            let _ = keyboard.tick();
        }

        if keyboard_timer.wait().is_ok() {
            let mut r_state: u64 = 0;
            for row in (0..3).into_iter() {
                r_state |= key_matrix.poll_row_state(row, &mut row_pins, &col_pins) as u64;
            }
            let l_state: u64 = match i2c.read(0x33, &mut i2c_buf) {
                Ok(()) => u32::from_be_bytes(i2c_buf) as u64,
                Err(_) => 0,
            };
            
            let state = l_state | (r_state << 21);
            kallisto.get_report(state);
            // The above code may be  somewhat time consuming so we check if we need to tick here
            if tick_timer.wait().is_ok() {
                let _ = keyboard.tick();
            }
            report_buf = [Keyboard::NoEventIndicated; 32];
            i = 0;
            while rx.ready() {
                report_buf[i] = rx.dequeue().unwrap();
                i += 1;
            }
            let _ = keyboard.device().write_report(report_buf);
        }

        if tick_timer.wait().is_ok() {
            let _ = keyboard.tick();
        }

        if usb_dev.poll(&mut [&mut keyboard]) {
            match keyboard.device().read_report() {
                Err(UsbError::WouldBlock) => {
                    //do nothing
                }
                Err(e) => {
                    loop {
                        led_pin.set_high().unwrap();
                        delay.delay_ms(100);
                        led_pin.set_low().unwrap();
                        delay.delay_ms(100);
                    }
                }
                Ok(leds) => {
                    led_pin.set_state(PinState::from(leds.num_lock)).ok();
                }
            }
        }

        if led_timer.wait().is_ok() {
            for (i, led) in leds.iter_mut().enumerate() {
                // An offset to give 3 consecutive LEDs a different color:
                let hue_offs = match i % 3 {
                    1 => 0.25,
                    2 => 0.5,
                    _ => 0.0,
                };

                let sin_11 = sin((t + hue_offs) * 2.0 * core::f32::consts::PI);
                // Bring -1..1 sine range to 0..1 range:
                let sin_01 = (sin_11 + 1.0) * 0.5;

                let hue = 360.0 * sin_01;
                let sat = 1.0;
                let val = 1.0;

                let rgb = hsv2rgb_u8(hue, sat, val);
                *led = rgb.into();
            }

            ws.write(brightness(leds.iter().copied(), strip_brightness))
                .unwrap();

            t += (17.0 / 1000.0) * animation_speed;
            while t > 1.0 {
                t -= 1.0;
            }
        }
    }
}

pub fn hsv2rgb(hue: f32, sat: f32, val: f32) -> (f32, f32, f32) {
    let c = val * sat;
    let v = (hue / 60.0) % 2.0 - 1.0;
    let v = if v < 0.0 { -v } else { v };
    let x = c * (1.0 - v);
    let m = val - c;
    let (r, g, b) = if hue < 60.0 {
        (c, x, 0.0)
    } else if hue < 120.0 {
        (x, c, 0.0)
    } else if hue < 180.0 {
        (0.0, c, x)
    } else if hue < 240.0 {
        (0.0, x, c)
    } else if hue < 300.0 {
        (x, 0.0, c)
    } else {
        (c, 0.0, x)
    };
    (r + m, g + m, b + m)
}

pub fn hsv2rgb_u8(h: f32, s: f32, v: f32) -> (u8, u8, u8) {
    let r = hsv2rgb(h, s, v);

    (
        (r.0 * 255.0) as u8,
        (r.1 * 255.0) as u8,
        (r.2 * 255.0) as u8,
    )
}

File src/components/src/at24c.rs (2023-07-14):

/*
* Code fore interacting with the AT24C256C and AT24C128C flash memory chips
*/
use embedded_hal::blocking::i2c::{Write, Read};
use rp_pico::hal;

const DEVICE_ADDRESS: u8 = 0b1010000;

pub enum I2cError {
    ReadError,
    WriteError,
}

pub enum At24cError {
    I2cError(I2cError),
    // Raised when a a buffer larger than 64 bytes is written
    InvalidSize,
    AddressOutOfRange,
}

impl Into<At24cError> for I2cError {
    fn into(self) -> At24cError {
        At24cError::I2cError(self)
    }
}

#[repr(u16)]
pub enum At24cMemSize {
    Kb128 = 128,
    Kb256 = 256,
}

pub struct At24c<'t, T> {
    size: At24cMemSize,
    i2c: T,
    tx_buffer: [u8; 66],
    last_write: u32,
    timer: &'t hal::Timer,
}

impl<'t, T: Read + Write> At24c<'t, T> {
    pub fn new(i2c: T, size: At24cMemSize, timer: &'t hal::Timer) -> At24c<'t, T> {
        At24c {
            size,
            i2c,
            timer,
            tx_buffer: [0; 66],
            last_write: 0
        }
    }


    // The AT24C* supports sequential reads of up to 64 bytes during at once
    pub fn read(&mut self, address: u16, buf: &mut [u8]) -> Result<(), At24cError> {
        // Check address and page boundries
        let _ = self.is_address_valid(address)?;
        if buf.len() > 64 {
            return Err(At24cError::InvalidSize);
        }

        let addrs_hi = ((address & 0xFF00) >> 8) as u8;
        let addrs_lo = (address & 0x00FF) as u8;
        self.wait_write_cycle();
        match self.i2c.write(DEVICE_ADDRESS, &[addrs_hi, addrs_lo]) {
            Ok(..) => {},
            Err(_) => return Err(I2cError::WriteError.into()), 
        }
        match self.i2c.read(DEVICE_ADDRESS, buf) {
            Ok(..) => {},
            Err(_) => return Err(I2cError::ReadError.into()), 
        }
        Ok(())
    }

    // The AT24C* support page writes of up to 64 bytes during
    // a single write cycle
    pub fn write(&mut self, address: u16, buf: &[u8]) -> Result<(), At24cError> {
        // Check address and page boundries
        let _ = self.is_address_valid(address)?;
        if buf.len() > 64 {
            return Err(At24cError::InvalidSize);
        }

        buf.iter().enumerate().for_each(|(i, b)| self.tx_buffer[2 + i] = *b);

        let addrs_hi = ((address & 0xFF00) >> 8) as u8;
        let addrs_lo = (address & 0x00FF) as u8;
        self.tx_buffer[0] = addrs_hi;
        self.tx_buffer[1] = addrs_lo;

        self.wait_write_cycle();
        match self.i2c.write(DEVICE_ADDRESS, &self.tx_buffer) {
            Ok(..) => {},
            Err(_) => return Err(I2cError::WriteError.into()), 
        }
        self.last_write = self.timer.get_counter_low();
        self.clear_tx_buffer();
        Ok(())
    }

    // The AT24C256C and AT24C128C have a maximum read cycle time of 5ms
    // after a write the internal write cycle time starts and you are not
    // allowed to read/write to the device during this time
    // If the last write happened later than 5ms ago this function blocks
    // until 5ms have passed
    pub fn wait_write_cycle(&self) {
        while self.timer.get_counter_low() - self.last_write < 5000 {
            cortex_m::asm::nop(); 
        }
    }

    // Checks that the requrested address is within the address range
    // of the device
    fn is_address_valid(&self, address: u16) -> Result<(), At24cError> {
        match self.size {
            At24cMemSize::Kb128 => {
                if address >= 16_384 {
                    return Err(At24cError::AddressOutOfRange);
                }
            },
            At24cMemSize::Kb256 => {
                if address >= 32_768 {
                    return Err(At24cError::AddressOutOfRange);
                }
            },
        }
        Ok(())
    }

    fn clear_tx_buffer(&mut self) {
        self.tx_buffer.iter_mut().for_each(|b| *b = 0);
    }
}
